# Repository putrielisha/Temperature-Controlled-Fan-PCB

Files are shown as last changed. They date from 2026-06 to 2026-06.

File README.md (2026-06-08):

# Temperature-Controlled-Fan-PCB
Temperature-controlled fan system implemented using a custom PCB designed in Autodesk EAGLE and embedded C firmware for real-time thermal regulation.

# Overview
This project is a microcontroller-based temperature-controlled cooling system designed using a custom PCB created in Autodesk EAGLE. The system reads real-time temperature data and automatically controls a USB fan based on a defined threshold using embedded C firmware.

# Features
- Real-time temperature monitoring via ADC
- Automatic fan ON/OFF control based on threshold value
- Custom PCB designed using Autodesk EAGLE
- Embedded C firmware for microcontroller logic
- USB-powered fan output control

# System Workflow
Temperature sensor → Microcontroller → Threshold comparison → GPIO output → Fan control

# Hardware Design
- Custom PCB designed using Autodesk EAGLE
- Fabricated through an external PCB manufacturing company arranged by the school
- Microcontroller-based control system for temperature monitoring and fan actuation
- USB-powered output stage for fan control

# Firmware
The firmware was developed in C (Microchip Studio) and handles:
- ADC-based temperature reading
- Conversion of sensor values into temperature
- Comparison against preset threshold values
- GPIO-based fan control output

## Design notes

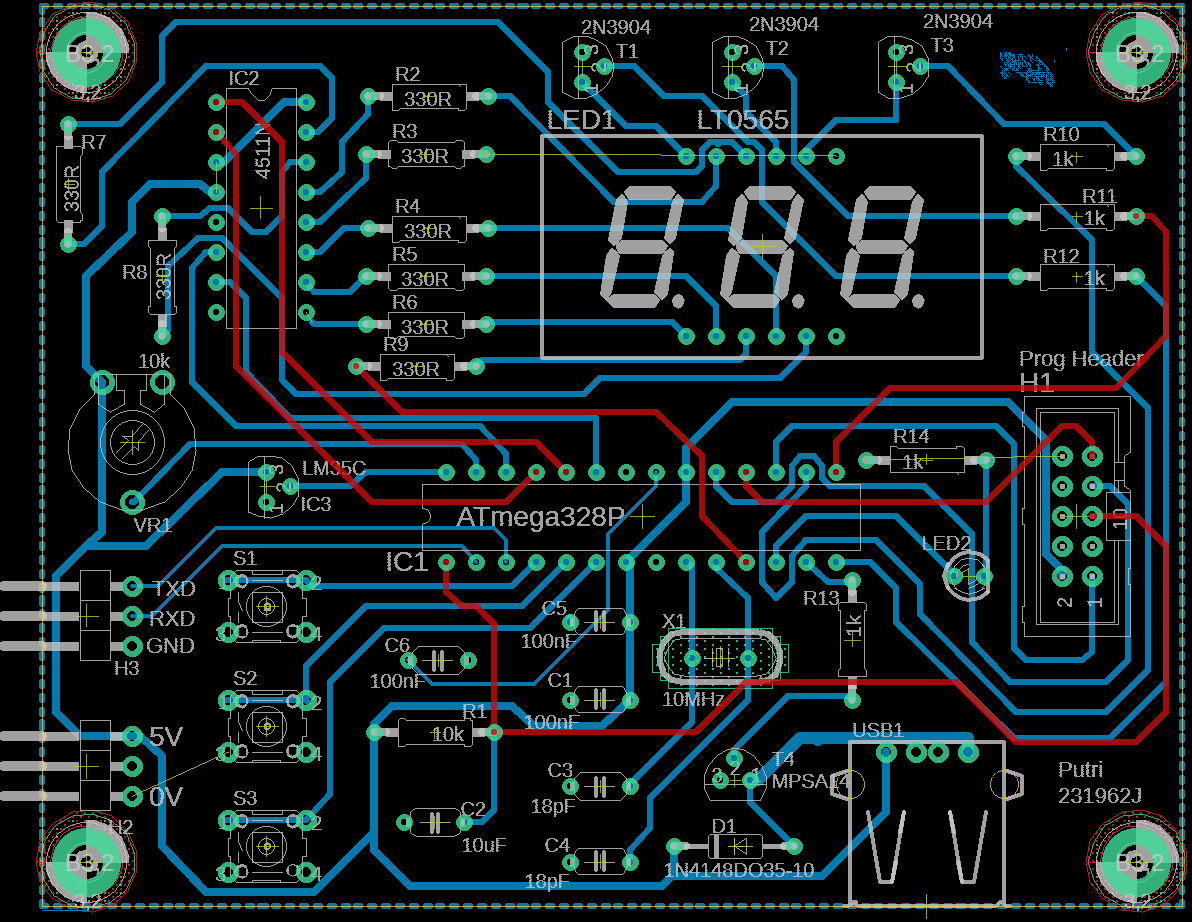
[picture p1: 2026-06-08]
Hardware/PCB/MCU Standard.png

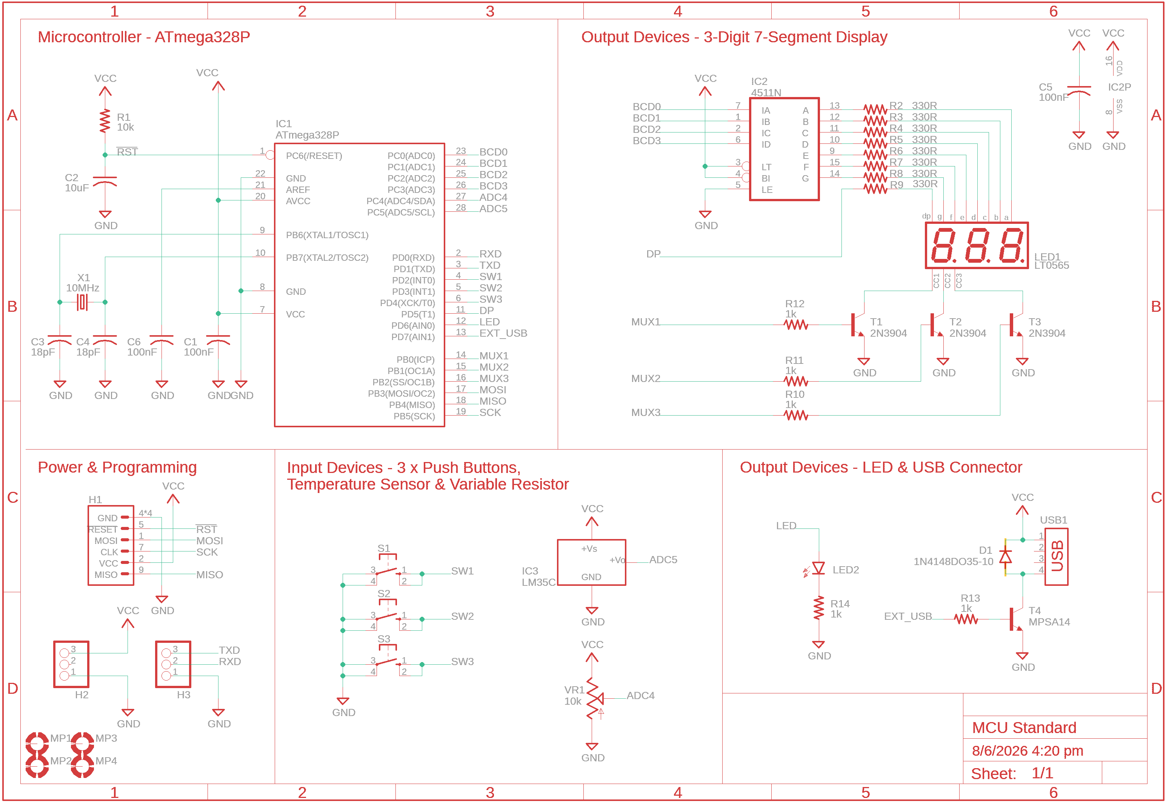
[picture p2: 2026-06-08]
Hardware/Schematic/MCU Standard.png

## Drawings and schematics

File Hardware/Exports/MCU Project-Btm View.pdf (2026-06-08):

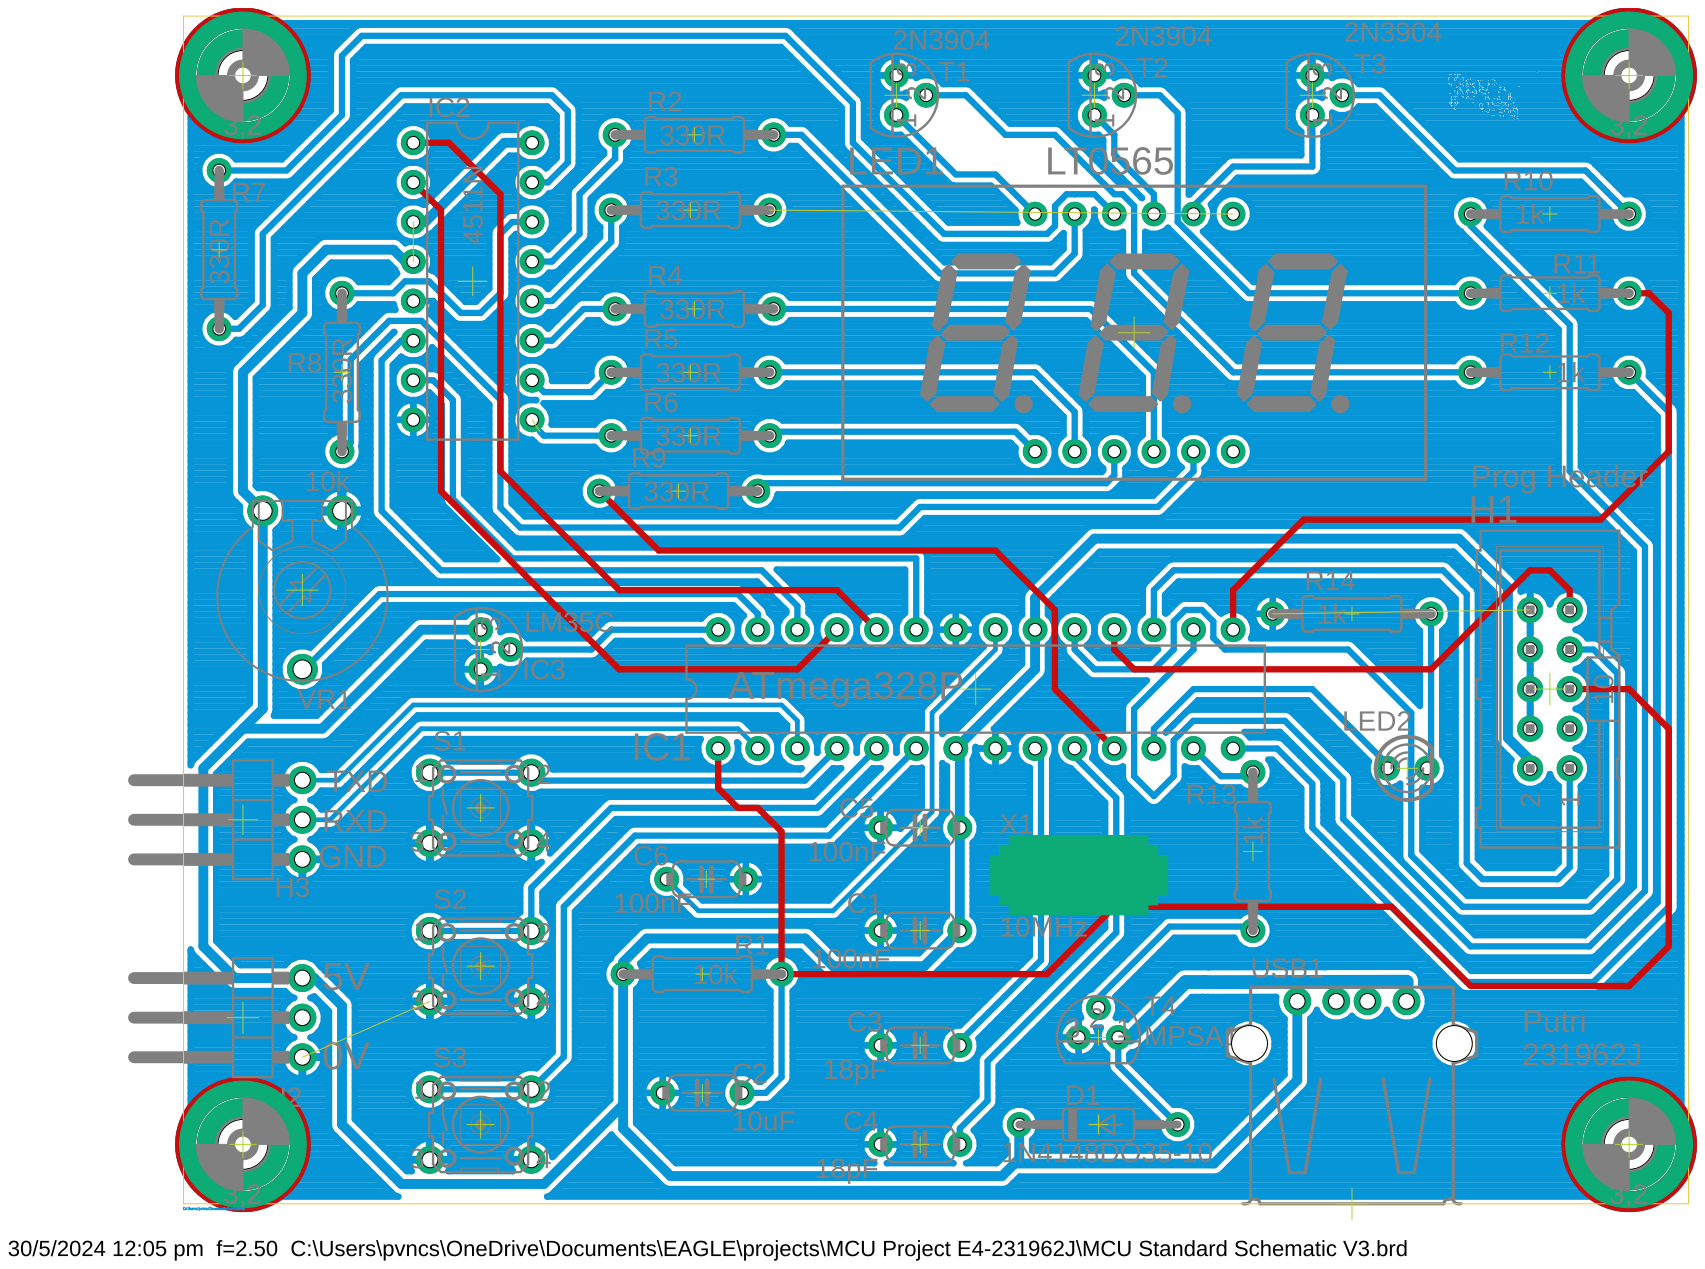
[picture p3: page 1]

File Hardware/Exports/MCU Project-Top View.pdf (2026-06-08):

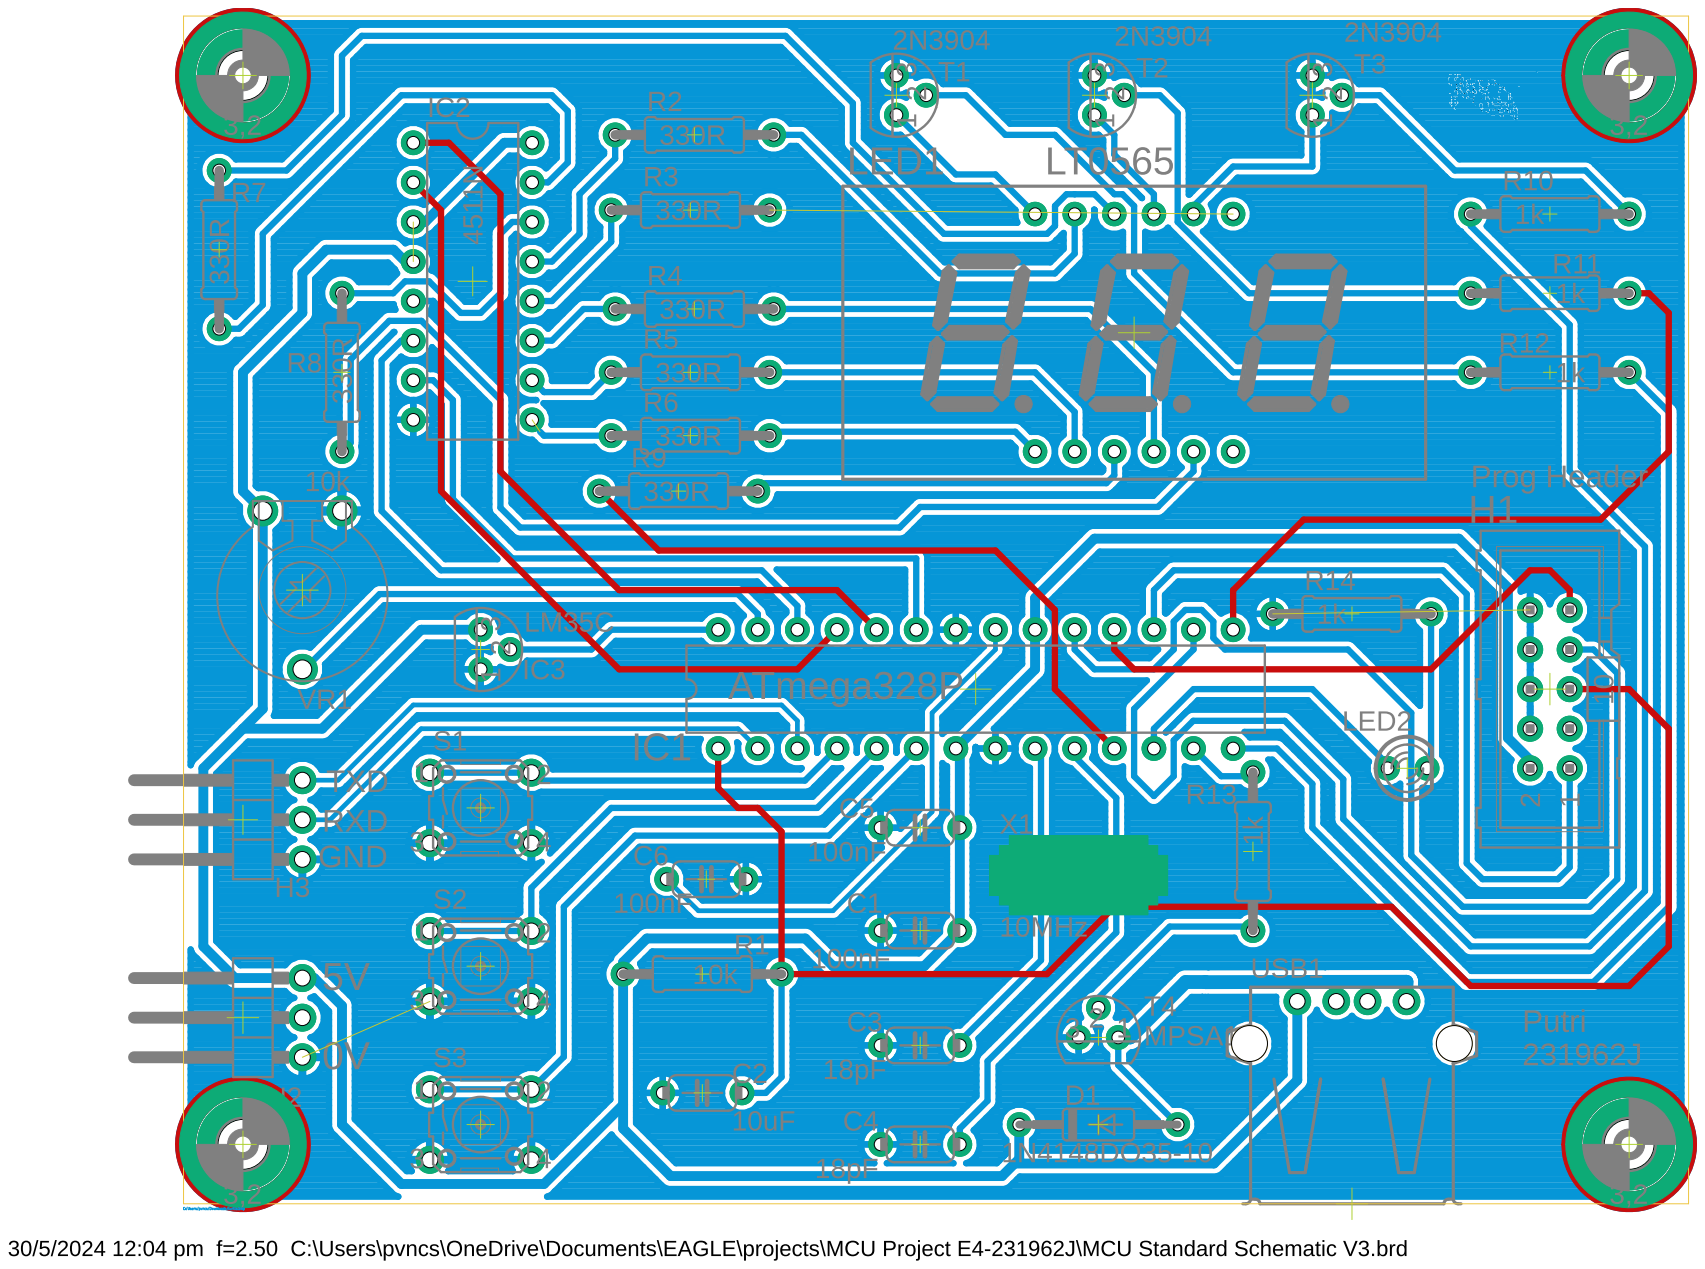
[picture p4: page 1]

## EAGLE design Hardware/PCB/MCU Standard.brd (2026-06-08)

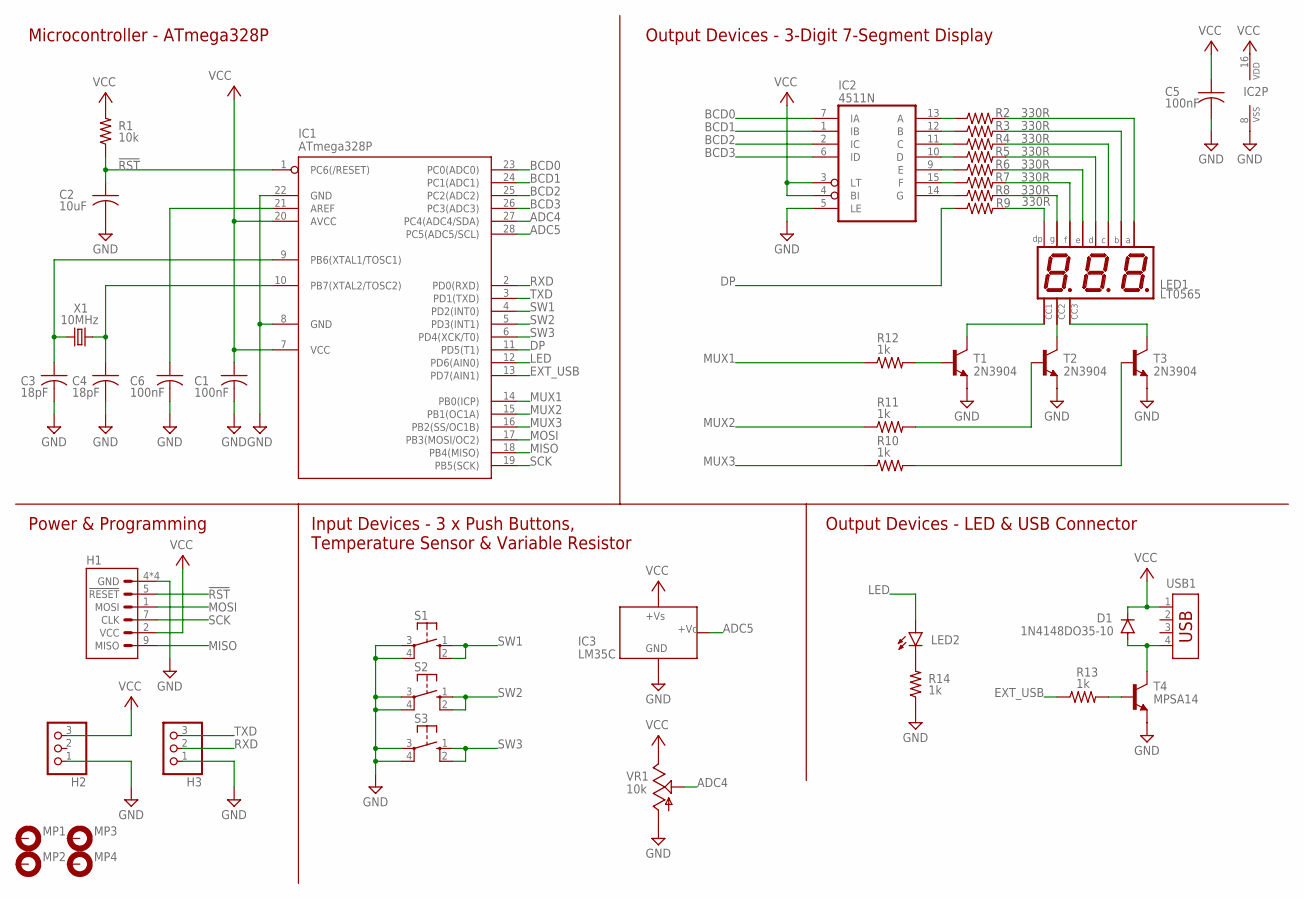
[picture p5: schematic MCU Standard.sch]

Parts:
C1, C5, C6: 100nF; C050-024X044
C2: 10uF; C050-024X044
C3, C4: 18pF; C050-024X044
D1: 1N4148DO35-10; DO35-10
H1: MISO_MOSI_IPC-10V; IDC-10V
H2, H3: PINHD-1X03_2.54-90°; 1X03/90
IC1: ATmega328P; DIL28-3
IC2: 4511N; DIL16
IC3: LM35C; TO92
LED1: LT0565; BX56/BX55
LED2: LED3MM
MP1, MP2, MP3, MP4: MOUNT-PAD-ROUND3.2; 3,2-PAD
R1: 10k; 0207/10
R2, R3, R4, R5, R6, R7, R8, R9: 330R; 0207/10
R10, R11, R12, R13, R14: 1k; 0207/10
S1, S2, S3: 10-XX; B3F-10XX
T1, T2, T3: 2N3904; TO92
T4: MPSA14; TO92
USB1: USB-787616; USB
VR1: 10k; PT-10
X1: 10MHz; HC49/S

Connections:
!RST: C2.1, H1.5 (!RESET), IC1.1 (PC6(/RESET)), R1.1
ADC4: IC1.27 (PC4(ADC4/SDA)), VR1.3 (S)
ADC5: IC1.28 (PC5(ADC5/SCL)), IC3.2 (VO)
BCD0: IC1.23 (PC0(ADC0)), IC2.7 (IA)
BCD1: IC1.24 (PC1(ADC1)), IC2.1 (IB)
BCD2: IC1.25 (PC2(ADC2)), IC2.2 (IC)
BCD3: IC1.26 (PC3(ADC3)), IC2.6 (ID)
DP: IC1.11 (PD5(T1)), R9.1
EXT_USB: IC1.13 (PD7(AIN1)), R13.1
GND: C1.2, C2.2, C3.2, C4.2, C5.2, C6.2, H1.4 (GND), H1.6 (GND), H1.8 (GND), H1.10 (GND), H2.1, H3.1, IC1.8 (GND), IC1.22 (GND), IC2.5 (LE), IC2.8 (VSS), IC3.1 (GND), R14.1, S1.3, S1.4 (P1), S2.3, S2.4 (P1), S3.3, S3.4 (P1), T1.3 (E), T2.3 (E), T3.3 (E), T4.3 (E), VR1.1 (A)
LED: IC1.12 (PD6(AIN0)), LED2.A
MISO: H1.9 (MISO), IC1.18 (PB4(MISO))
MOSI: H1.1 (MOSI), IC1.17 (PB3(MOSI/OC2))
MUX1: IC1.14 (PB0(ICP)), R12.1
MUX2: IC1.15 (PB1(OC1A)), R11.1
MUX3: IC1.16 (PB2(SS/OC1B)), R10.1
unnamed: C3.1, IC1.9 (PB6(XTAL1/TOSC1)), X1.1
unnamed: C4.1, IC1.10 (PB7(XTAL2/TOSC2)), X1.2
unnamed: LED1.5 (G), R8.2
unnamed: LED1.10 (F), R7.2
unnamed: LED1.1 (E), R6.2
unnamed: LED1.2 (D), R5.2
unnamed: LED1.4 (C), R4.2
unnamed: LED1.7 (B), R3.2
unnamed: LED1.11 (A), R2.2
unnamed: IC2.13 (A), R2.1
unnamed: IC2.12 (B), R3.1
unnamed: IC2.11 (C), R4.1
unnamed: IC2.10 (D), R5.1
unnamed: IC2.9 (E), R6.1
unnamed: IC2.15 (F), R7.1
unnamed: IC2.14 (G), R8.1
unnamed: LED1.3 (DP), R9.2
unnamed: C6.1, IC1.21 (AREF)
unnamed: LED1.8 (CA), T3.1 (C)
unnamed: LED1.9 (CA), T2.1 (C)
unnamed: LED1.12 (CA), T1.1 (C)
unnamed: R10.2, T3.2 (B)
unnamed: R11.2, T2.2 (B)
unnamed: R12.2, T1.2 (B)
unnamed: R13.2, T4.2 (B)
unnamed: D1.A, T4.1 (C), USB1.4
unnamed: LED2.K (C), R14.2
RXD: H3.2, IC1.2 (PD0(RXD))
SCK: H1.7 (CLK), IC1.19 (PB5(SCK))
SW1: IC1.4 (PD2(INT0)), S1.1 (S), S1.2 (S1)
SW2: IC1.5 (PD3(INT1)), S2.1 (S), S2.2 (S1)
SW3: IC1.6 (PD4(XCK/T0)), S3.1 (S), S3.2 (S1)
TXD: H3.3, IC1.3 (PD1(TXD))
VCC: C1.1, C5.1, D1.C, H1.2 (VCC), H2.3, IC1.7 (VCC), IC1.20 (AVCC), IC2.3 (LT), IC2.4 (BI), IC2.16 (VDD), IC3.3 (+VS), R1.2, USB1.1, VR1.2 (E)

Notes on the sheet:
Power & Programming
Input Devices - 3 x Push Buttons, Temperature Sensor & Variable Resistor
Output Devices - LED & USB Connector
Output Devices - 3-Digit 7-Segment Display
Microcontroller - ATmega328P

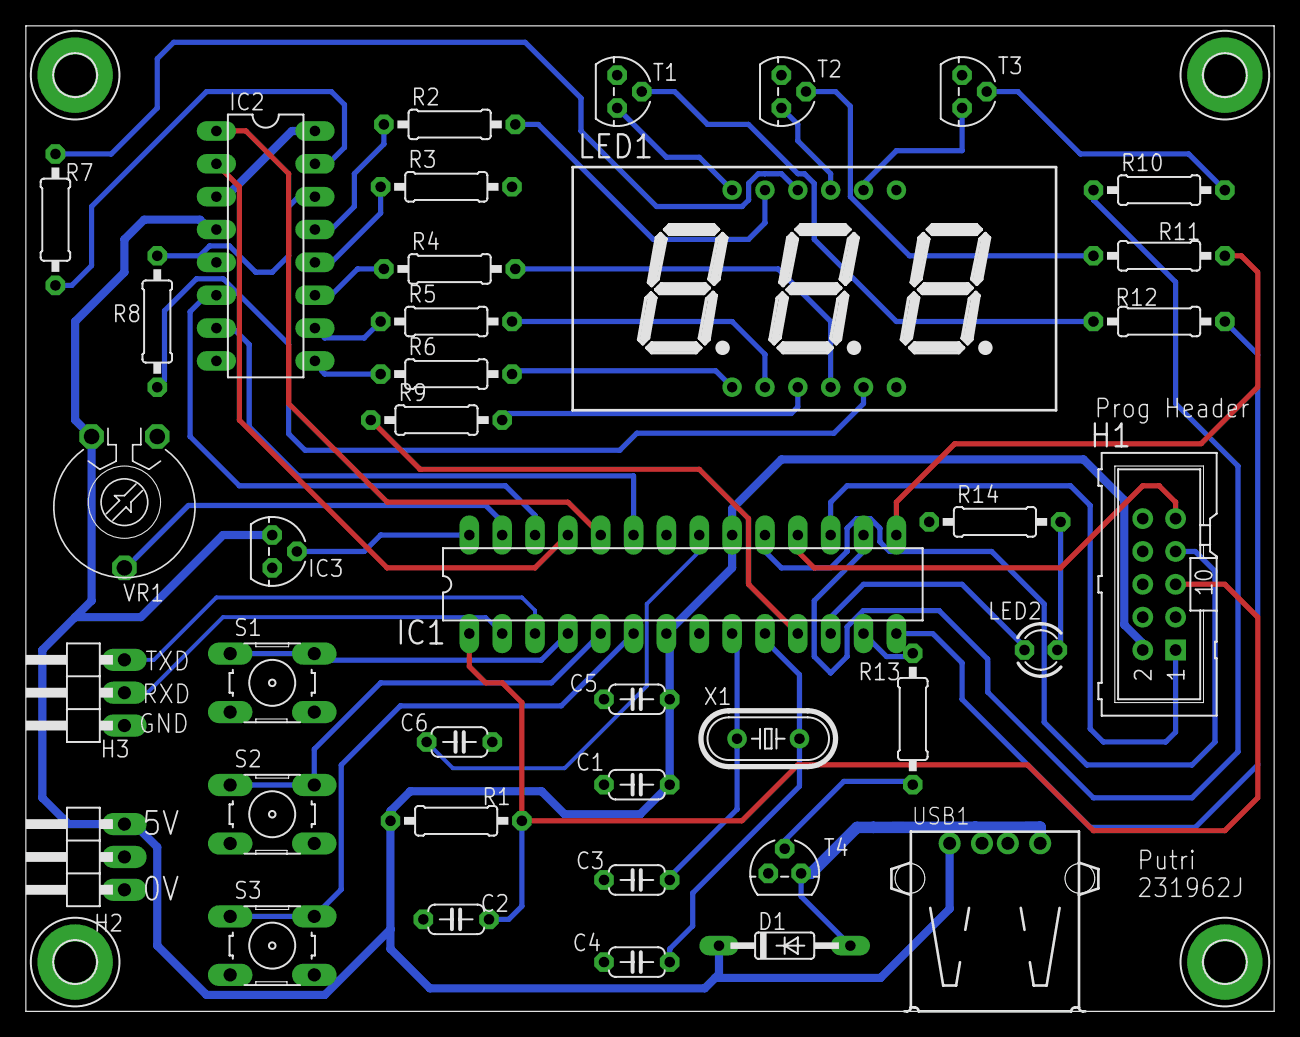
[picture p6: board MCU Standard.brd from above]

Board: 2 copper layers, 96.5 x 76.2 mm, 43 parts (0 on the bottom side), 50 nets.

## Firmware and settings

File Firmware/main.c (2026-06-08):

#include <avr/io.h>
#include <avr/interrupt.h>
#define TurnOnTemp 26
#define TurnOffTemp 25

void delay(unsigned long k){	//delay function with argument
	while(--k!=0);
}

void display(unsigned int num){	//function to display num value at 3-digit 7 seg display
	unsigned char a,b,c,x;
	a = num/100;	//split num into 3 individual digit a,b,c using formulae
	b = (num%100)/10;
	c = num%10;
	for(x=0;x<100;x++){
		PORTB = (PORTB & 0xF8)| 0x01;	//on left digit
		PORTC = (PORTC & 0xF0)| a;	//display value a at left digit
		delay(100);
		PORTB = (PORTB & 0xF8)| 0x02;	//on middle digit
		PORTC = (PORTC & 0xF0)| b;	//display value b at middle digit
		delay(100);
		PORTB = (PORTB & 0xF8)| 0x04;	//on right digit
		PORTC = (PORTC & 0xF0)| c;	//display value c in right digit
		delay(100);
	}
}

void ADC_Init(){
	DIDR0 = 0x20; // Disable digital.
	DDRC = DDRC & ~(0x20);	//PC5=Input.
	PORTC = PORTC & ~(0x30);	// Enable ADC & set clock.
	ADCSRA |= 0x87;
	ADMUX = 0xC0; //Vref=1.1V
}

unsigned int ADC_Read(){	// Select PC5 as input.
	ADMUX = (ADMUX & 0xF0) | 0x05;
	ADCSRA |= 0x40; // Start ADC.
	while ((ADCSRA & 0x10)==0); //Wait.
	ADCSRA |= 0x10; // Reset.
	return ADCW;
}

int convert(unsigned int adcValue){
	unsigned long c;
	c = (long) adcValue * 1075;	//multiply 1075
	adcValue = c/1000;	//divide by 1000
	return(adcValue);	//adcValue is converted to measured temp & return to calling function
}

// ||EXPERIMENTAL||
// int main(){
// 	unsigned int adcValue;
// 	DDRC |= 0x0F; // Configure output.
// 	DDRB |= 0x07; // Configure output.
// 	DDRD |= 0x80;
// 	ADC_Init();
// 	while(1){
// 		adcValue = ADC_Read();
// 		display(adcValue);
// 	}
//
unsigned int dpNum;
unsigned char whichDigit=1, subSec=0;

void delay2(unsigned long w){
	while(w--!=0);
}

// ||EXPERIMENTAL INTERRUPT||
// ISR(TIMER0_OVF_vect) {
// 	unsigned char digit;
// 	TCNT0 = 0x81;	//set 5msec timer
// 	subSec++;
// 	if (subSec==200){
// 		subSec=0;
// 		dpNum++;
// 		if (dpNum>999) dpNum=0;
// 	}
// 	switch(whichDigit){
// 		case 1: digit = dpNum/100;
// 		PORTB = (PORTB & 0xf8)| 0x01;
// 		PORTC = (PORTC & 0XF0)| digit;
// 		break;
// 		case 2: digit = (dpNum%100)/10;
// 		PORTB = (PORTB & 0xf8)| 0x02;
// 		PORTC = (PORTC & 0XF0)| digit;
// 		break;
// 		case 3: digit = dpNum%10;
// 		PORTB = (PORTB & 0xf8)| 0x04;
// 		PORTC = (PORTC & 0XF0)| digit;
// 		break;
// 	}
// 	whichDigit++;
// 	if (whichDigit>3) whichDigit=1;
// }
// 
// void initTimer0(){
// 	TCNT0 = 0x81; // set 0.5s timer
// 	TIFR0 |= 0x01; // Clear Overflow Flag.
// 	TCCR0B = (TCCR0B & 0xF8)| 0x05;	// Start timer.
//
// ||EXPERIMENTAL||
// int main2(void)
// {
// 	DDRC = 0x0F;	//set PC0-PC3 as output, PC4-PC7 as input
// 	DDRB = 0x07;	//Set PB0-PB2 as output for MUX1, MUX2 & MU3
// 	DDRD = 0x80;
// 	TIMSK0 |= 0x01;	// Enable Timer 1 Interrupt
// 	sei();
// 	initTimer0();
// 	while(1){	//do nothing
// 	}
// }

int main(void) {
	unsigned int adcValue;
	DDRC |= 0x0F; // Configure PC0-PC3 as output
	DDRB |= 0x07; // Configure PB0-PB3 as output
	DDRD |= 0x80;
	ADC_Init();
	while (1){
		adcValue = ADC_Read();
		int temperature = convert(adcValue);
		display(temperature);
		if (temperature >= TurnOnTemp) {
			PORTD |= 0x08; // Turn on fan (PB3 = High, 0x08)
			} else if (temperature <= TurnOffTemp) {
			PORTD &= ~0x08; // Turn off fan (PB3 = Low, 0x08)
		}
	}
}
